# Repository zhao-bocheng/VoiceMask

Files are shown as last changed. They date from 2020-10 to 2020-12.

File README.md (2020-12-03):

# Voice Mask

该面罩是基于Arduino Nano制作的一款声控灯光面罩，面罩的灯光图案可以根据声音的变化而变化，模仿说话时的嘴部动作，另外还能通过声音控制显现一个简单的微笑。附带有颜色随身边温度变化、颜色自定义、静态图像切换的小功能。（[*演示视频*](./video/voiceMask.mp4)）

## 功能介绍

### 1. 显示模式

显示模式有两种：动态和静态。
a) 动态模式下说话时图案会根据声音大小不同进行不同的变化，当发出一个短促的声音并且一定时间内无其他声响，会显露一个“微笑”；（[*演示视频*](./video/voiceMask.mp4)）
b) 静态（禁言）模式下可以切换三种静态图像：“禁止标志”、风车、爱心

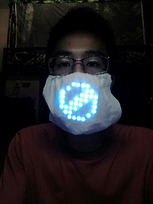
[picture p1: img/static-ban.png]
Ban 禁止标志
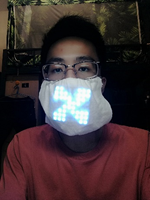
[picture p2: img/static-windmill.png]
Windmill 风车图案
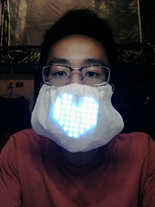
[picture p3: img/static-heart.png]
heart 爱心图案


### 2. 颜色模式

颜色模式有两种：温变模式和自定义模式。
a) 温变模式下，颜色会时刻根据当下温度进行变化：随着温度升高灯光颜色偏向暖色调，随着温度降低灯光颜色偏向冷色调，可以间接的反应温度变化（y源代码中将温度区间设置为10到40摄氏度）；\
b) 自定义模式下可以自定义当前颜色，这种模式下颜色固定为所调节的颜色（颜色范围为彩虹色，没有白光）

### 补充说明

a) 以上个功能（模式）的切换和使用通过面罩上的按钮进行；\
b) 每次断电后开发板会记住上次断电前面罩所处状态；\
c) 该程序由两个程序组成:主程序和附属程序。附属程序“putDataIntoEEPROM.ino”用于向EEPROM写入一些状态值，以设置默认的初始状态（对于未下载过该程序的开发板最好先下载“putDataIntoEEPROM.ino”来对EEPROM中的数据进行初始化）

## 硬件需求

| **设备** | **数量** |
| :---: | :---: |
| Arduino Nano | 1 |
| 立式轻触按键 | 若干 |
| 8x8WS2812点阵 | 1 |
| 面包线、跳线等导线 | 若干 |
| 面包板（主要用于测试阶段） | 1 |
| 10k电阻 | 1 |
| NTC热敏电阻 | 1 |
| MAX4466声音传感器 | 1 |
| 洞洞板（用于承载按键，尺寸按情况决定） | 1 |
| 可透光、透气且有一定韧性的布料 | 尺寸自定 |
| 9V电池 | 1 |
| 9V电池扣 | 1 |
| 5v输出降压模块 | 1 |
| 热缩管 | 若干 |
| 焊锡工具 | 配套工具若干 |

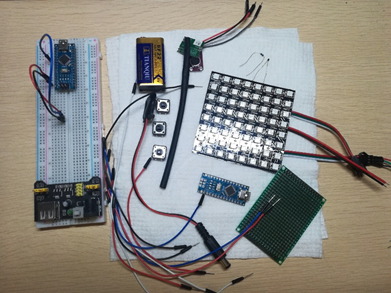
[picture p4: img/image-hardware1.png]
hardware 使用的硬件


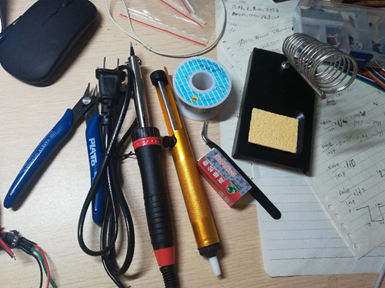
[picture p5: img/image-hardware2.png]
hardware 使用的硬件


## 软件需求

Arduino IDE: Arduino IDE 要与Arduino单片机型号配套（这里为Arduino Nano），其支持C/C++开发语言且可以同时兼容两种语言，易上手。该代码编写需要引入以下库：

```c
#include <Adafruit_GFX.h>
#include <Adafruit_NeoPixel.h>
#include <Adafruit_NeoMatrix.h>
#include <gamma.h>
#include <math.h>
#include <EEPROM.h>
```

fritzing（可选）：用于绘制原理图。

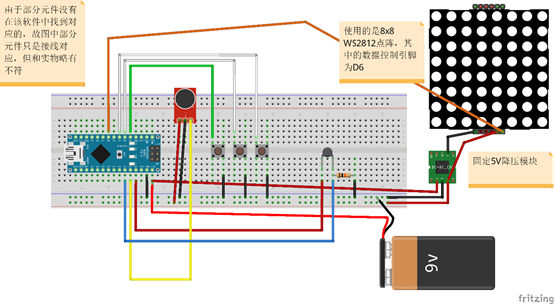
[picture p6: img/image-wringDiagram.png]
Wring Diagram 绘制的接线图


## 制作成果展示

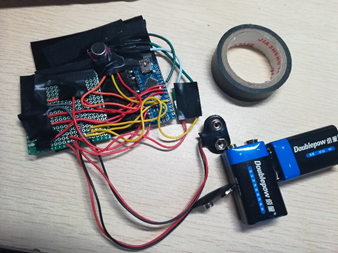
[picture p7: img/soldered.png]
soldered 半成品


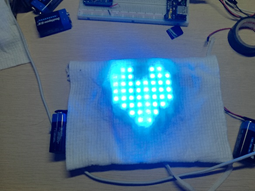
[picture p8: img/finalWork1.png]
final work 成品


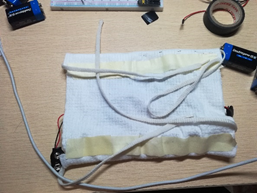
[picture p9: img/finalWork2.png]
fianl work 成品


final work 成品

*制作过程不做赘述，可参考库中的[设计工作记录](./设计工作记录.pdf)*

## 存在问题

即使最后的成品是以两个9V的电池供电，仍因为电力消耗大容易导致电力不足，继而使灯光效果出现瑕疵。另外，在面罩上加装9V电池，实属突兀。

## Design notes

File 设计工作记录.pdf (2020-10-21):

### 设计工作记录

周次 | 时间 | 设计进展概述 | 阶段成果截图 | 思考、讨论和改进意见

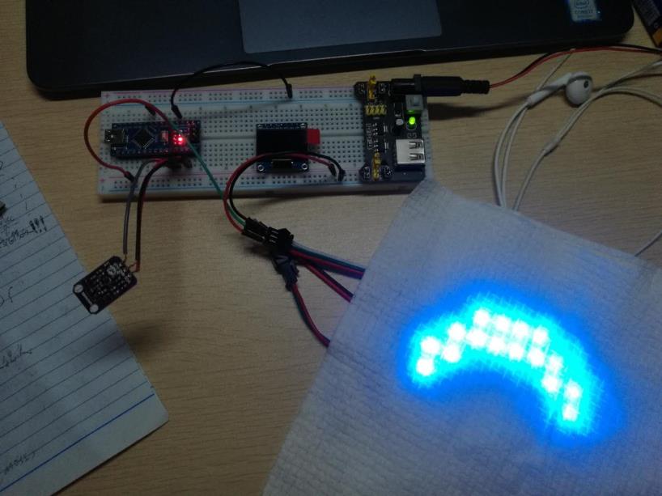
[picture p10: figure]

一 | 8.28

制作 voice mask 最基本功
能：动态功能——说话时点
阵会发生图像变化，并已经
可以根据声音做出一个简单
“微笑”

最基本的功能已经实现，但代
码步骤略显繁琐，需要精简基
本功能代码；考虑增添一些附
加功能

### 设计工作记录

周次 | 时间 | 设计进展概述 | 阶段成果截图 | 思考、讨论和改进意见

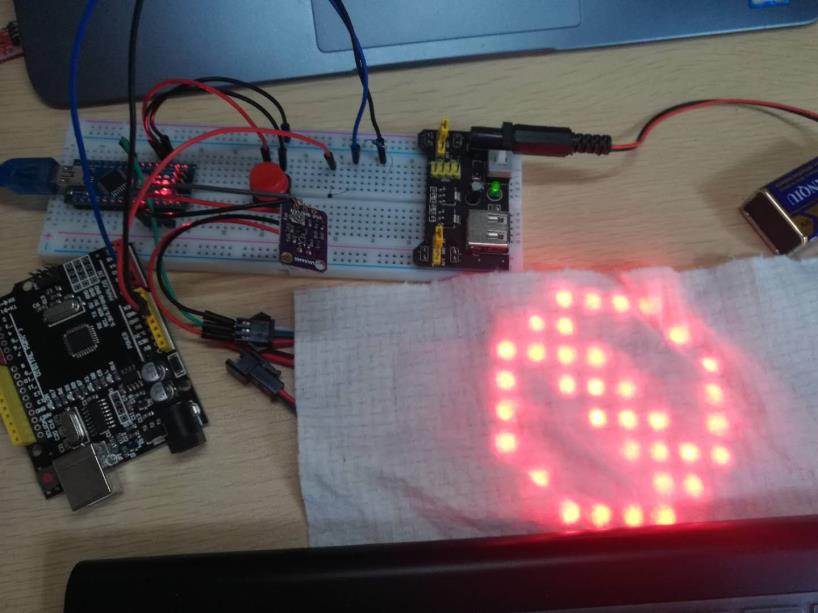
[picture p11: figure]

一 | 8.29

精简了“动态模式”的相关
代码，增添了一个“静态模
式”，“动态模式”和“静
态模式”可以通过红色按钮
切换

功能添加成功，但代码中对颜
色值的赋予似乎略显繁琐，待
改进；代码量变多，程序代码
结构略显混乱

### 设计工作记录

周次 | 时间 | 设计进展概述 | 阶段成果截图 | 思考、讨论和改进意见
一 | 8.29

修改代码中的颜色赋予步
骤；将“动态模式”和“静
态模式”相关代码精简，暂
时不考虑将这两个模式的代
码模块化为函数，担心不断
地调用函数会影响连续的动
态效果

颜色始终固定，考虑配合已有
的 NTC 热敏电阻开发出可以根
据温度变化颜色的功能

### 设计工作记录

周次 | 时间 | 设计进展概述 | 阶段成果截图 | 思考、讨论和改进意见

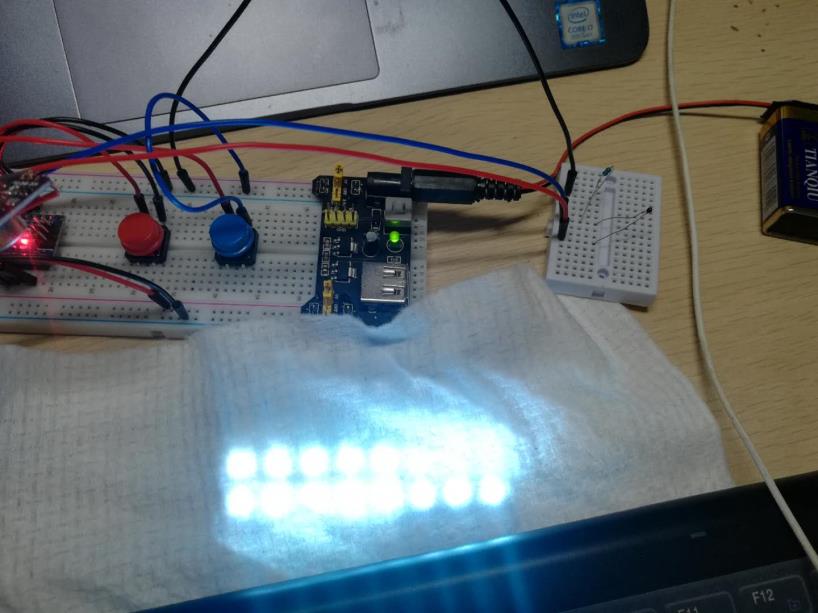
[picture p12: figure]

一 | 8.30

基本实现颜色随温度变化的
功能，可以通过蓝色按钮进
行该功能的开关

原先设想的是：随着温度升高
灯光颜色偏向暖色调，随着温
度降低灯光颜色偏向冷色调，
但展现出的效果并非如此，需
要改变有关于根据温度值变化
计算出的颜色值的算法（现有
算法仅为 currentColor =
map(temperature, minTemp,
maxTemp, 0x1F, 0xF800),0x1F 为十六位颜色的蓝色，0xF800
位红色）

### 设计工作记录

周次 | 时间 | 设计进展概述 | 阶段成果截图 | 思考、讨论和改进意见

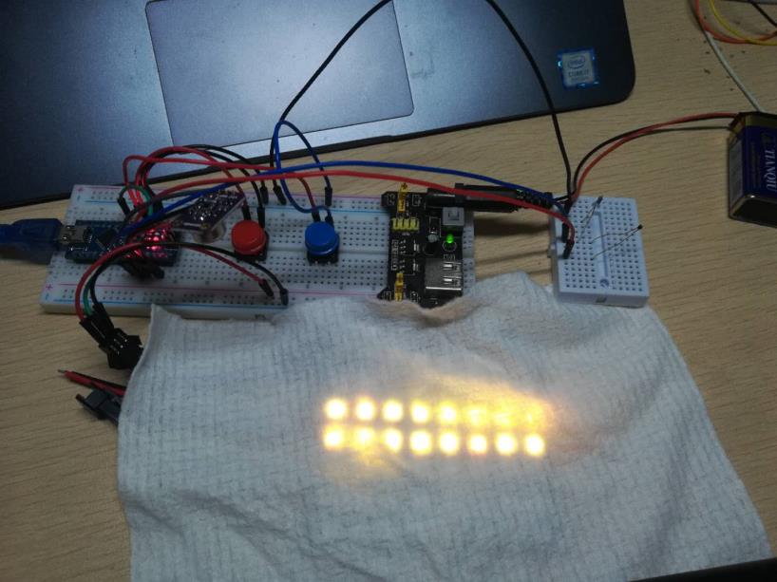
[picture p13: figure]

一 | 8.31

将颜色值随温度变化的算法
进行了修改，并整合到了
getColor()函数中（详见源
代码）

此时“动态模式”出现迟缓现
象，需要进一步优化代码

### 设计工作记录

周次 | 时间 | 设计进展概述 | 阶段成果截图 | 思考、讨论和改进意见

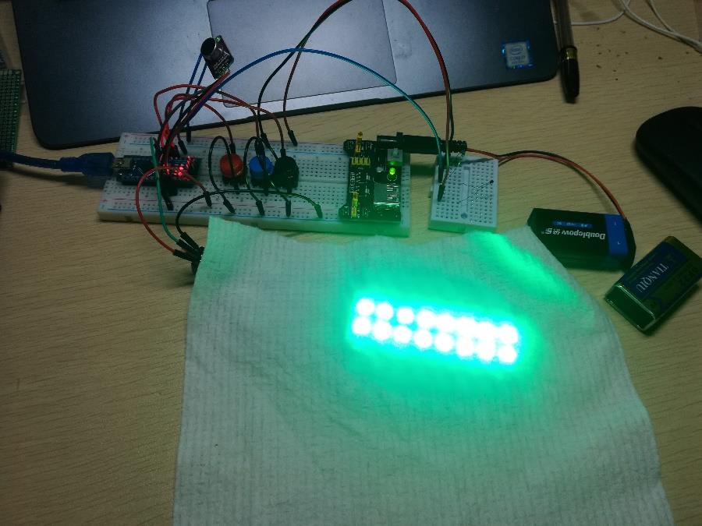
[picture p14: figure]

一 | 9.1

将先前的所有各功能进行了
模块化，都整合到了各自函
数里，并针对使用的各个变
量的不同性质，将可以放入
flash 空间的数据放入，尽
量减少对 SRAM 的占用，动
态效果得到了很大改善；在
修改代码的同时我添加了之
前忽略掉的颜色调节，可以
通过黑色按钮在彩虹色中选
择颜色，没有白光，当处于
“温变模式”时，无法自行
改变颜色

设想的是按照彩虹色的顺序，
由蓝到红，再经过紫色回到蓝
的顺序单向调节想要的颜色，
但是调节过程中颜色略有跳跃
和缺失

### 设计工作记录

周次 | 时间 | 设计进展概述 | 阶段成果截图 | 思考、讨论和改进意见

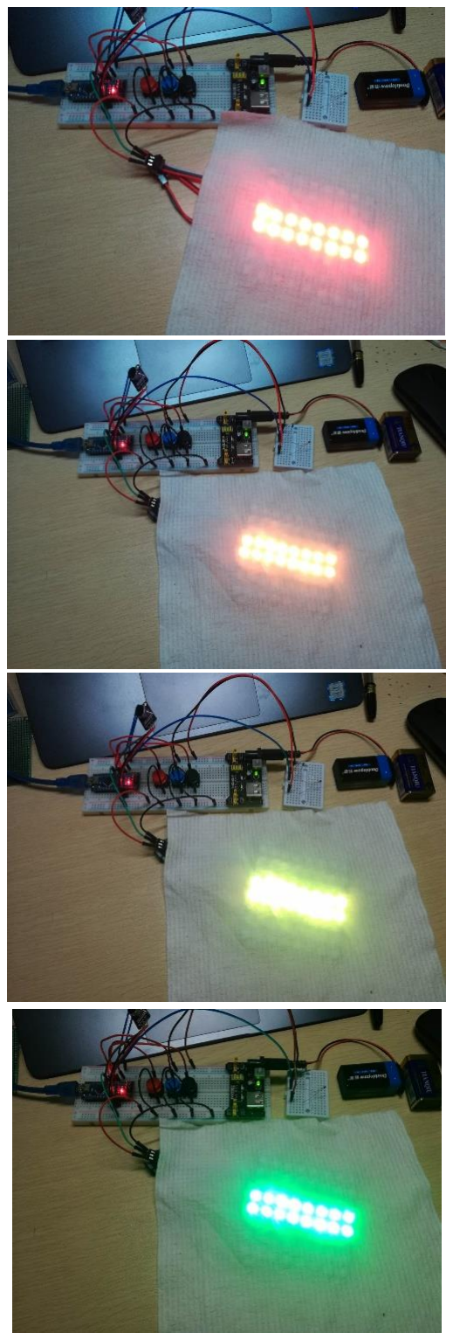
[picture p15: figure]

一 | 9.2

修改了变化颜色的算法，并
整合到了 getColor()函数
中，进一步精简代码，成功
实现颜色变化的设想顺序，
并且能得到许多介于七色之
间的颜色

基本设想已经基本实现，考虑
如何焊接并制作面罩

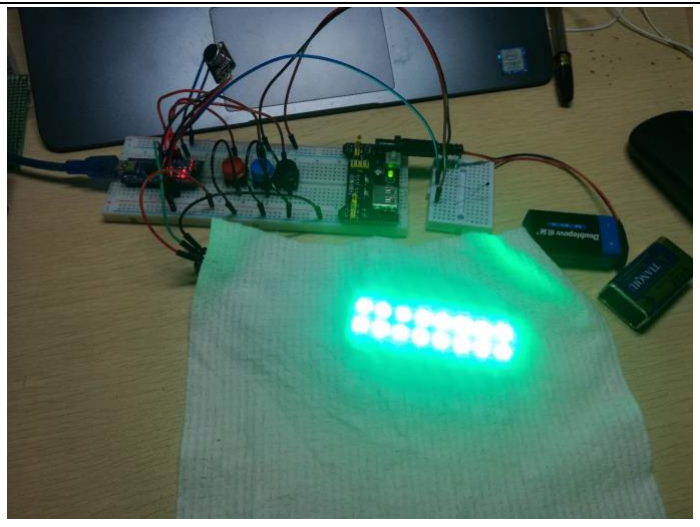
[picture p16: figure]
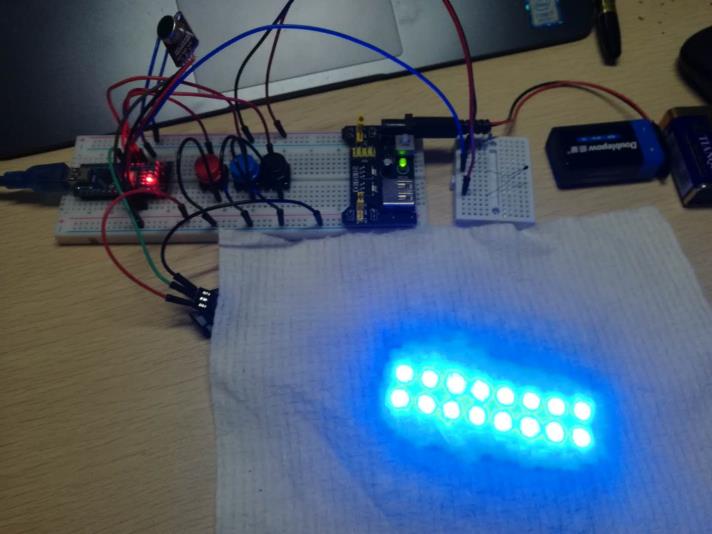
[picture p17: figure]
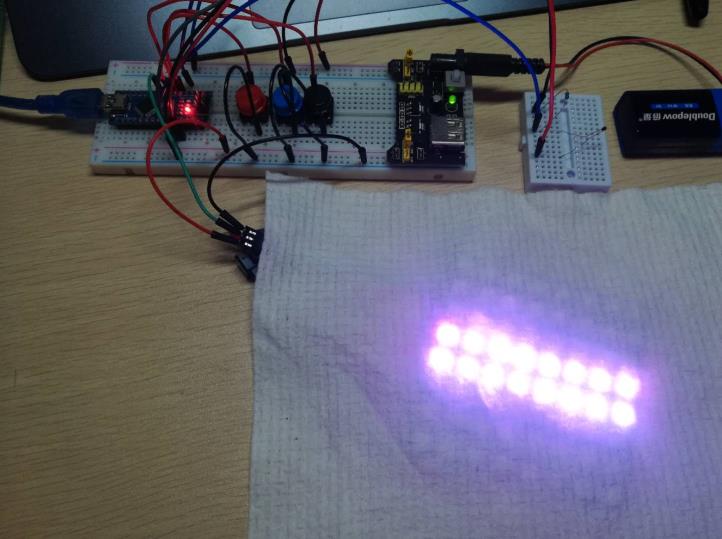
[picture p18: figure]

### 设计工作记录

周次 | 时间 | 设计进展概述 | 阶段成果截图 | 思考、讨论和改进意见

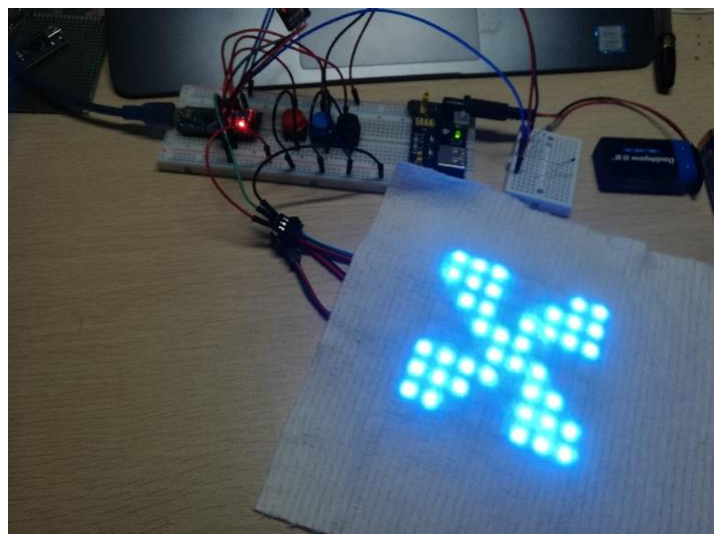
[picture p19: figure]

一 | 9.3

为静态模式增添多了两个静
态图案，现共三个静态图
案，通过红色按钮调节

准备焊接，并整合到面罩布料
中；另外由于每次断电后再接
电时数据就恢复为初始值，不
具有“记忆”，应寻求解决方
案

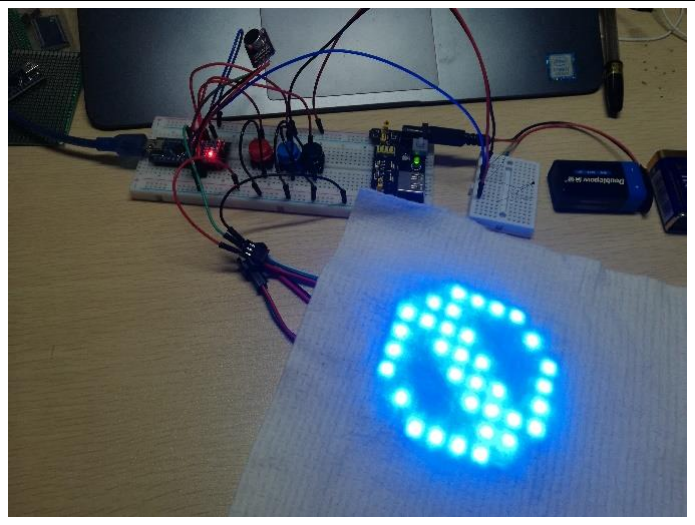
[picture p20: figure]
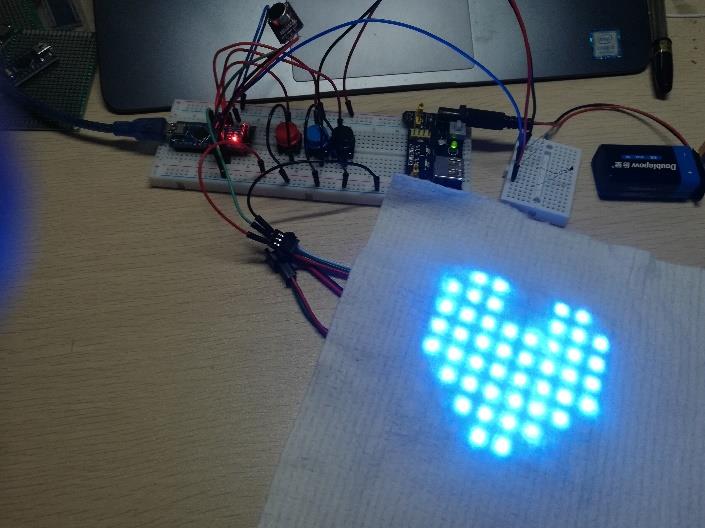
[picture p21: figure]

### 设计工作记录

周次 | 时间 | 设计进展概述 | 阶段成果截图 | 思考、讨论和改进意见
一 | 9.4

利用开发板的 EEPROM，将
颜色 RGB 值、模式状态值写
入其中，实现数据值断电后
不丢失的效果，为了初始化
这些特定值，需要在上传主
程序前上传一个附属程序
“putDataIntoEEPROM.ino
”，同时主程序代码步骤中
添加了相应的 EEPROM 读写
操作

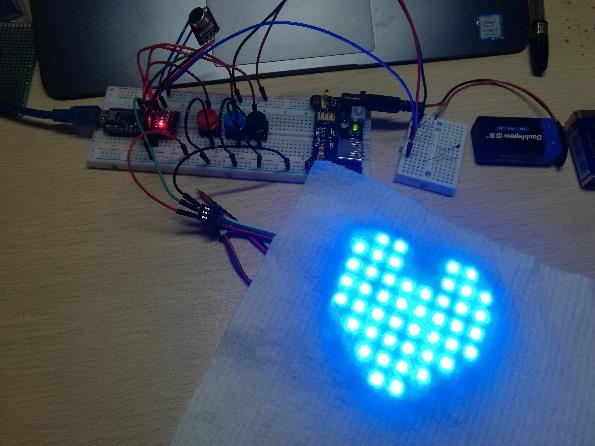
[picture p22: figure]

初始状态

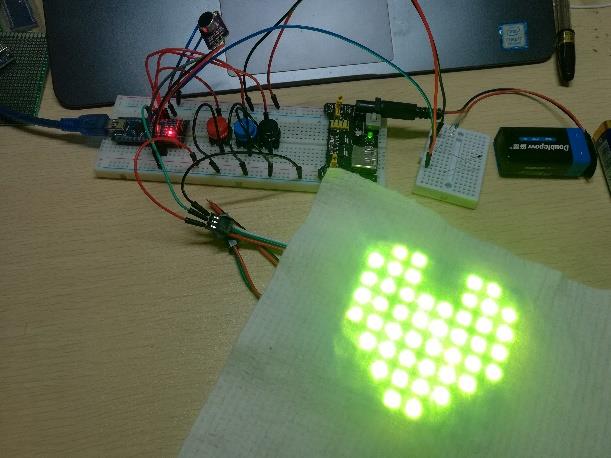
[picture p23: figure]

断电前

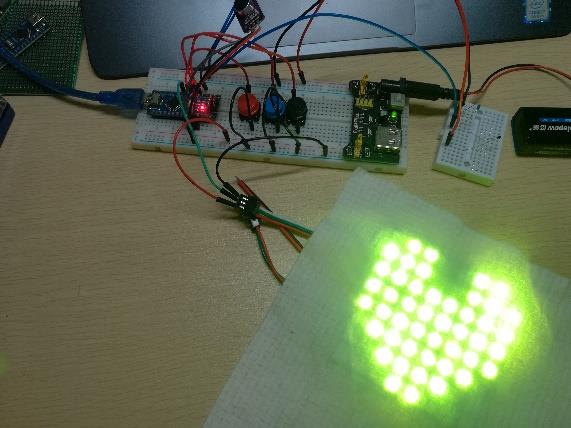
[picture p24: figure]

断电后再次接电

准备焊接，并整合到面罩布料
中

### 设计工作记录

周次 | 时间 | 设计进展概述 | 阶段成果截图 | 思考、讨论和改进意见

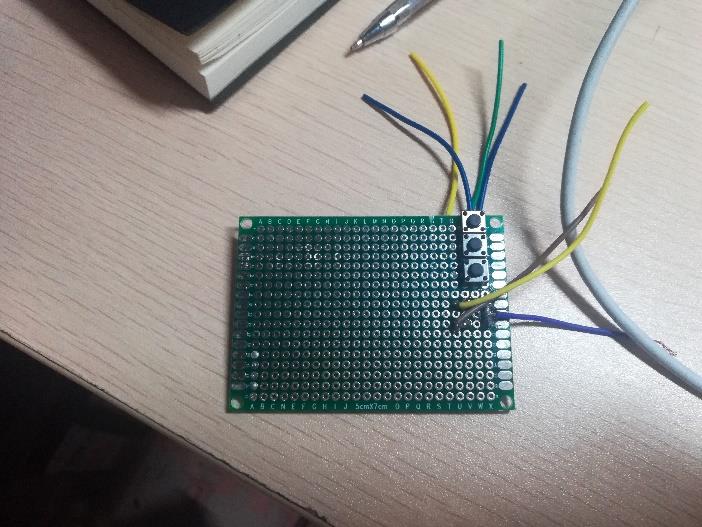
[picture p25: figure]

二 | 9.6 | 最后阶段——焊接所有元件

该焊接结果出现故障，并且使
用的电烙铁枪头氧化严重，导
致部分元件焊接时间过久因高
温而损坏，需要重新购买元件

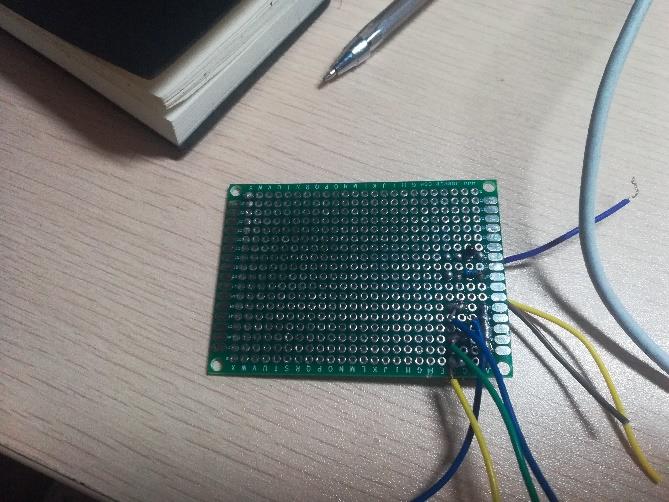
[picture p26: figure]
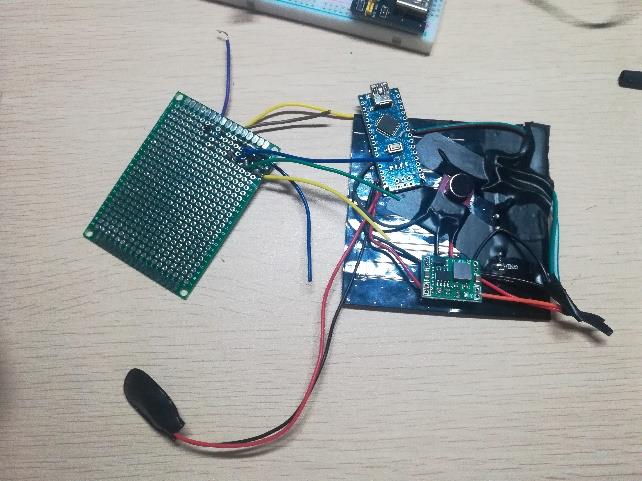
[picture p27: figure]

### 设计工作记录

周次 | 时间 | 设计进展概述 | 阶段成果截图 | 思考、讨论和改进意见

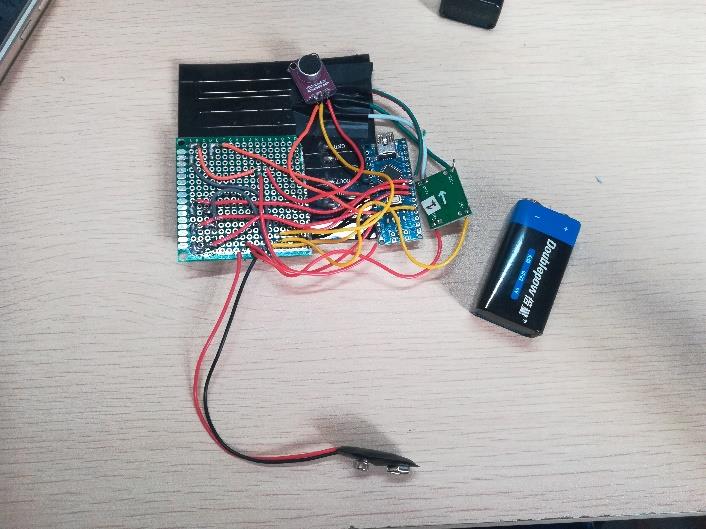
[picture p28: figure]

三 | 9.14 | 重新焊接所有元件

焊接完成，但是一个 9V 电池不
足以为所有元件供电，故需要
进行改进——打算再添加一个
9V 电池扣，以便一个 9V 电池
为 WS2812 点阵单独供电，另一
个 9V 电池为其他所有元件供电

### 设计工作记录

周次 | 时间 | 设计进展概述 | 阶段成果截图 | 思考、讨论和改进意见

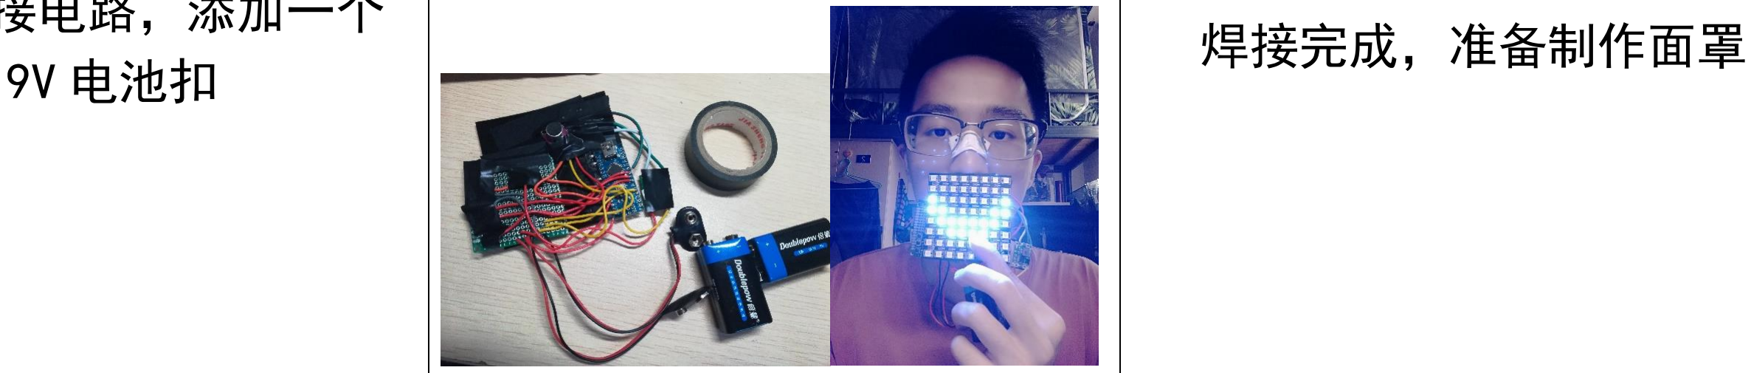
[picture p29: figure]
9V 电池扣; 焊接完成，准备制作面罩

三 | 9.15

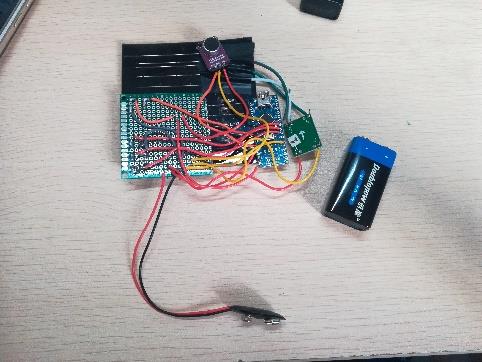
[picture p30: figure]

改进焊接电路，添加一个

### 设计工作记录

周次 | 时间 | 设计进展概述 | 阶段成果截图 | 思考、讨论和改进意见

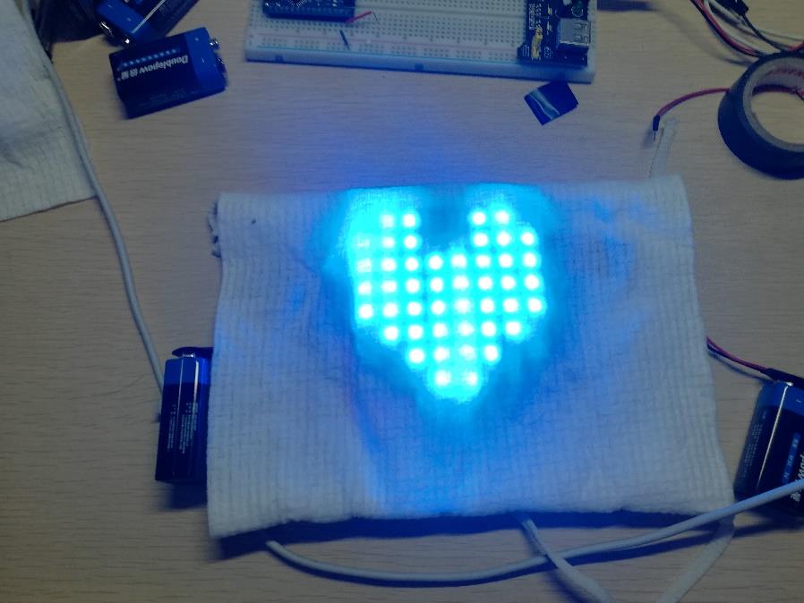
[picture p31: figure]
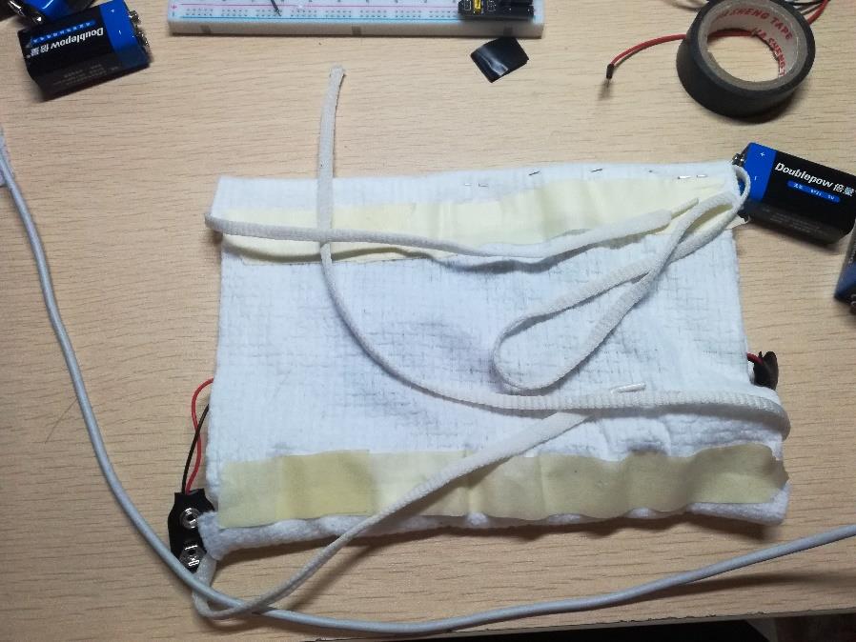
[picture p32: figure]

三 | 9.16

最后阶段（2）——面罩制
作

我的手工属实不忍直视

## 设计工作小结

学习经验：
不要在一个暂时无法解决的问题上纠结，出去找小
姐姐散散步也挺好，说不定回来就有灵感了

项目存在问题：
供电问题，通过 9V 电池为所有元件供电电量极易不
足，当电量不足时，灯光效果会出现偏差，尤其是颜
色；另外电源形式为一个立体长方体的 9V 电池，对一 个面罩来说实属突兀，应寻求体积更小、电量更足的
电源。
面罩透气性问题，由于面罩的正中就是一个方形密闭
材料的 WS2812 点阵，透气性显然很差，如果有条件， 或许可以把 WS2812 灯珠镶嵌在特定透气面料中，解 决透气性不足的问题。

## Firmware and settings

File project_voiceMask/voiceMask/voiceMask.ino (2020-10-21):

/*
 * 灯光面罩
 * 1、显示模式
 * 显示模式有两种：动态和静态
 * 动态模式下说话时图案会根据声音大小不同进行不同的变化，
 * 当发出一个短促的声音并且一定时间内无其他声响，会显露一个“微笑”
 * 静态（禁言）模式下可以切换三种静态图像：“禁止标志”、风车、爱心
 * 
 * 2、颜色模式
 * 颜色模式有两种：温变模式和自定义模式
 * 温变模式下，颜色会时刻根据当下温度进行变化：
 * 随着温度升高灯光颜色偏向暖色调，随着温度降低灯光颜色偏向冷色调，
 * 可以间接的反应温度变化
 * （以下代码中将温度区间设置为10到40摄氏度）
 * 自定义模式下可以自定义当前颜色，这种模式下颜色固定为所调节的颜色（颜色范围为彩虹色，没有白光）
 * 
 * 以上个功能（模式）的切换和使用通过面罩上的按钮进行
 * 
 * 每次断电后开发板会记住上次断电前面罩所处状态
 * 该程序有一个附属程序“putDataIntoEEPROM.ino”用于向EEPROM写入一些状态值，以设置默认的初始状态
 * （对于未下载过该程序的开发板最好先下载“putDataIntoEEPROM.ino”来对EEPROM中的数据进行初始化）
 * 
 */ 
#include <Adafruit_GFX.h>
#include <Adafruit_NeoPixel.h>
#include <Adafruit_NeoMatrix.h>
#include <gamma.h>
#include <math.h>
#include <EEPROM.h>

//以下为表情图案
const PROGMEM uint8_t mouth_0[8][8] = {
  {0,0,0,0,0,0,0,0},
  {0,0,0,0,0,0,0,0},
  {0,0,0,0,0,0,0,0},
  {6,6,6,6,6,6,6,6},
  {6,6,6,6,6,6,6,6},
  {0,0,0,0,0,0,0,0},
  {0,0,0,0,0,0,0,0},
  {0,0,0,0,0,0,0,0}
};

const PROGMEM uint8_t mouth_1[8][8] = {
  {0,0,0,0,0,0,0,0},
  {0,0,0,0,0,0,0,0},
  {0,0,0,6,6,0,0,0},
  {6,6,6,0,0,6,6,6},
  {6,6,6,0,0,6,6,6},
  {0,0,0,6,6,0,0,0},
  {0,0,0,0,0,0,0,0},
  {0,0,0,0,0,0,0,0}
};

const PROGMEM uint8_t mouth_2[8][8] = {
  {0,0,0,0,0,0,0,0},
  {0,0,0,0,0,0,0,0},
  {0,6,6,6,6,6,6,0},
  {6,0,0,0,0,0,0,6},
  {6,0,0,0,0,0,0,6},
  {0,6,6,6,6,6,6,0},
  {0,0,0,0,0,0,0,0},
  {0,0,0,0,0,0,0,0}
};

const PROGMEM uint8_t mouth_3[8][8] = {
  {0,0,0,0,0,0,0,0},
  {0,0,6,6,6,6,0,0},
  {0,6,0,0,0,0,6,0},
  {6,0,0,0,0,0,0,6},
  {6,0,0,0,0,0,0,6},
  {0,6,0,0,0,0,6,0},
  {0,0,6,6,6,6,0,0},
  {0,0,0,0,0,0,0,0}
};

const PROGMEM uint8_t mouth_4[8][8] = {
  {0,0,6,6,6,6,0,0},
  {0,6,0,0,0,0,6,0},
  {6,0,0,0,0,0,0,6},
  {6,0,0,0,0,0,0,6},
  {6,0,0,0,0,0,0,6},
  {6,0,0,0,0,0,0,6},
  {0,6,0,0,0,0,6,0},
  {0,0,6,6,6,6,0,0}
};

const PROGMEM uint8_t mouth_smile[8][8] = {
  {0,0,0,0,0,0,0,0},
  {0,0,0,0,0,0,0,0},
  {6,0,0,0,0,0,0,6},
  {6,6,0,0,0,0,6,6},
  {0,6,6,6,6,6,6,0},
  {0,0,6,6,6,6,0,0},
  {0,0,0,0,0,0,0,0},
  {0,0,0,0,0,0,0,0}
};

const PROGMEM uint8_t mouth_ban[8][8] = {
  {0,0,6,6,6,6,0,0},
  {0,6,6,0,0,0,6,0},
  {6,6,6,6,0,0,0,6},
  {6,0,6,6,6,0,0,6},
  {6,0,0,6,6,6,0,6},
  {6,0,0,0,6,6,6,6},
  {0,6,0,0,0,6,6,0},
  {0,0,6,6,6,6,0,0}
};

const PROGMEM uint8_t mouth_cross[8][8] = {
  {6,6,6,0,0,0,6,6},
  {6,6,6,0,0,6,6,6},
  {0,6,6,0,6,6,6,6},
  {0,0,6,6,6,0,0,0},
  {0,0,0,6,6,6,0,0},
  {6,6,6,6,0,6,6,0},
  {6,6,6,0,0,6,6,6},
  {6,6,0,0,0,6,6,6}
};

const PROGMEM uint8_t mouth_heart[8][8] {
  {0,6,6,0,0,6,6,0},
  {6,6,6,0,0,6,6,6},
  {6,6,6,6,6,6,6,6},
  {6,6,6,6,6,6,6,6},
  {6,6,6,6,6,6,6,6},
  {0,6,6,6,6,6,6,0},
  {0,0,6,6,6,6,0,0},
  {0,0,0,6,6,0,0,0}
};

const PROGMEM int imageTotal = 4; //图案显示种类, mouth_(num|smile)  mouth_ban  mouth_cross  mouth_heart

const PROGMEM int micPin = A7;  //声音传感器模拟输入引脚
const PROGMEM int matrixPin = 6;  //对WS2812点阵的数据输出引脚

//显示模式转换按钮相关变量
int imageNum;  //图像模式
const PROGMEM int displayModePin = 2; //显示模式切换按钮引脚

//颜色模式转换按钮相关变量
bool ifChange;  //颜色是否随温度改变
const PROGMEM int colorModePin = 3; //颜色模式切换按钮引脚
const PROGMEM int tempPin = A6; //温度传感器模拟值输入
//颜色随温度的变化范围
const PROGMEM int minTemp = 10; //celsius
const PROGMEM int maxTemp = 40;
//颜色变换按钮相关变量
const PROGMEM int colorChangePin = 4; //颜色值改变按钮引脚

//定义一个8x8WS2812点阵对象
Adafruit_NeoMatrix matrix = Adafruit_NeoMatrix(8, 8, matrixPin,
  NEO_MATRIX_TOP     + NEO_MATRIX_RIGHT +
  NEO_MATRIX_ROWS    + NEO_MATRIX_ZIGZAG,
  NEO_GRB            + NEO_KHZ800);
  
//颜色值已经用另一个程序“putColorIntoEEPROM.ino”写入EEPROM

void setup() {
  //设置各功能按钮引脚状态
  pinMode(displayModePin, INPUT_PULLUP);
  pinMode(colorModePin, INPUT_PULLUP);
  pinMode(colorChangePin, INPUT_PULLUP);

  //从EEPROM中读取数据
  EEPROM.get(3, ifChange);
  EEPROM.get(4, imageNum);

  //初始化点阵
  matrix.begin();

  //Serial.begin(9600);
}

void loop() {
  //动态模式
  imageNum = dynamicMode(imageNum, displayModePin);
  //禁言模式
  imageNum = banningMode(imageNum, displayModePin);
} 


//通过NTC热敏电阻的输入模拟值计算当前温度
double themistor(int rawADC) {
  double temp;
  temp = log((10240000/(rawADC)) - 10000);
  temp = 1/(0.001129148 + (0.000234125 + (0.0000000876741 * temp * temp)) * temp);
  temp = temp - 273.15;
  return temp;
}

//获取颜色
uint16_t getColor(bool ifChange) {
  uint8_t rval, gval, bval;
  //按不同的颜色模式处理rgb值
  if(ifChange) {
    //减小温度值的波动
    int samples = 128;
    long analog = 0;
    for(int i = 0; i < samples; i ++) {
      analog += analogRead(tempPin);
    }
    analog = analog / samples;
    double temperature = themistor((int)analog); //去多个模拟值的平均值，减小温度值波动
    //根据温度不同进行不同处理
    if(temperature < minTemp) {
      rval = 0;
      gval = 0;
      bval = 255;
    }else if(temperature > maxTemp) {
      rval = 255;
      gval = 0;
      bval = 0;
    }else {
      rval = map(temperature, minTemp, maxTemp, 0, 255);
      bval = map(temperature, minTemp, maxTemp, 255, 0);
      gval = 510 - rval - bval;
    }
  }else {
    //取得颜色值
    EEPROM.get(0, rval);  
    EEPROM.get(1, gval);
    EEPROM.get(2, bval);
    int ifValChange = digitalRead(colorChangePin);
    if(ifValChange == 0){
      if(bval == 255 && gval != 255 && rval == 0) {
        gval += 5;
      }else if(bval != 0 && gval == 255) {
        bval -= 5;
      }else if(gval == 255 && rval !=255) {
        rval += 5;
      }else if(gval != 0 && rval == 255) {
        gval -= 5;
      }else if(rval == 255 && bval != 255) {
        bval += 5;
      }else if(rval != 0 && bval == 255) {
        rval -= 5;
      }
      //记录新的颜色值
      EEPROM.put(0, rval);  
      EEPROM.put(1, gval);
      EEPROM.put(2, bval);
      
      //delay(10); //debounce
    }
  }
  uint16_t colorval = matrix.Color(rval, gval, bval);
  return colorval;
}

//显示相应图案
void drawImage(short image_addr, bool ifChange){
  uint16_t currentColor; //当前颜色
  //判断颜色是否随温度变化,并按对应模式给予颜色
  currentColor = getColor(ifChange);
  //给灯珠填充颜色
  for(int x = 0; x<8; x++){
    for(int y = 0; y<8; y++){
      //注意以下代码中来自avr/pgmspace.h的pgm_byte_xx()函数
      uint8_t index = pgm_read_byte_near(image_addr+x+y*8); //从flash程序空间中读取表情图案数据
      //uint8_t index = pgm_read_byte((short)mouth_ban+x+y*8);
      //uint16_t currentColor;// = pgm_read_word_near(palette + index);
      
      //向位于(x,y)的点写入颜色
      if(index == 0) {
        matrix.drawPixel(x, y, (uint16_t)0x0); 
      }else {
        matrix.drawPixel(x, y, currentColor);
      }
    }
  }
  matrix.show();
}

//动态模式
int dynamicMode(int imageNum, int disPlayModePin) {
  int popDetection = 0; //检测到符合条件的峰值的次数
  const static int PROGMEM noDetectionT = 500; //ms 没有检测到符合条件峰值的间隔时间阈值
  bool smiling = false; //是否微笑状态
  const static int PROGMEM smileLasting = 2000; //ms 微笑保持时间
  unsigned long smiletimer = 0; //微笑保持时间计时
  unsigned long last_face = 0;  //上一次表情状态时间点
  
  const static int PROGMEM peakThreshold = 150; //峰值绝对值的阈值
  const static int PROGMEM mouth1Threshold = 150; //mouth_1的显示阈值
  const static int PROGMEM mouth2Threshold = 200; //mouth_2的显示阈值
  const static int PROGMEM mouth3Threshold = 300; //mouth_3的显示阈值
  const static int PROGMEM mouth4Threshold = 400; //mouth_4的显示阈值
  const static uint16_t PROGMEM samples = 128; //取128个模拟值样本
  const static int PROGMEM micThreshold = 512; //声音传感器阈值，实际操作时阈值大小大概在500到550间

  //切换按钮状态值
  int oldStateDisplay = 1;
  int newStateDisplay;

  int oldStateColor = 1;
  int newStateColor;
  
  while(imageNum == 0) {
    float micAbsPeak = 0; //峰值的绝对值
    for (int i = 0; i < samples; i ++){
      auto analog = analogRead(micPin);
      auto micLine = abs(analog - micThreshold);
      
      micAbsPeak = max(micLine, micAbsPeak);
    }
    
    if(micAbsPeak > peakThreshold){
      popDetection += 1;
      if(popDetection > 2) {
        smiling = false;
        last_face = millis();
      }
    }else{
      if(popDetection > 0 && popDetection <= 2) {
        if(millis() > last_face + noDetectionT){
          smiling = true;
          smiletimer = millis() + smileLasting;
        }
      }
      popDetection = 0; //这个很关键
    }
  
    if(millis() > smiletimer) 
      smiling = false;
  
    //以下的micAbsVal全部改用micAbsPeak
    if(smiling){
      drawImage((short)mouth_smile, ifChange);
    }else if(micAbsPeak < mouth1Threshold){
      drawImage((short)mouth_0, ifChange);
    }else if(micAbsPeak < mouth2Threshold){
      drawImage((short)mouth_1, ifChange);
    }else if(micAbsPeak < mouth3Threshold){
      drawImage((short)mouth_2, ifChange);
    }else if(micAbsPeak < mouth4Threshold){
      drawImage((short)mouth_3, ifChange);
    }else {
      drawImage((short)mouth_4, ifChange);
    }
    
    //显示模式切换按钮
    newStateDisplay = digitalRead(displayModePin);
    if(newStateDisplay == 1 && oldStateDisplay == 0){
      imageNum = (imageNum + 1) % imageTotal;
      EEPROM.put(4, imageNum);
    }
    oldStateDisplay = newStateDisplay;

    //颜色模式切换按钮
    newStateColor = digitalRead(colorModePin);
    if(newStateColor == 1 && oldStateColor == 0) {
      ifChange = !ifChange;
      EEPROM.put(3, ifChange);
    }
    oldStateColor = newStateColor;
  }
  return imageNum;
}

//禁言模式
int banningMode(int imageNum, int displayModePin) {
  //切换按钮状态值
  int oldStateDisplay = 1;
  int newStateDisplay;

  int oldStateColor = 1;
  int newStateColor;
  
  while(imageNum != 0) {
    if(imageNum == 1) {
      drawImage((short)mouth_ban, ifChange);  //禁止标志图案
    }else if(imageNum == 2) {
      drawImage((short)mouth_cross, ifChange); //X图案
    }else if(imageNum == 3) {
      drawImage((short)mouth_heart, ifChange); //X图案
    }
    //显示模式切换按钮
    newStateDisplay = digitalRead(displayModePin);
    if(newStateDisplay == 1 && oldStateDisplay == 0){
      imageNum = (imageNum + 1) % imageTotal;
      EEPROM.put(4, imageNum);
    }
    oldStateDisplay = newStateDisplay;

    //颜色模式切换按钮
    newStateColor = digitalRead(colorModePin);
    if(newStateColor == 1 && oldStateColor == 0) {
      ifChange = !ifChange;
    }
    oldStateColor = newStateColor;
  }
  return imageNum;
}

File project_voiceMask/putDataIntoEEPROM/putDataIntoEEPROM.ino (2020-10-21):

/*
 * putDataIntoEEFROM.ino
 * 这是一个初始化开发板EEPROM的程序，目的只是要把一个颜色值、模式状态放入
 */
#include <EEPROM.h>

void setup() {
  // put your setup code here, to run once:
  uint8_t rval = 0;
  uint8_t gval = 0;
  uint8_t bval = 255;
  int imageNum = 0;
  bool ifChange = true;
//  int address = 0;
  //写入EEPEOM
  EEPROM.put(0, rval);  
  EEPROM.put(1, gval);
  EEPROM.put(2, bval);
  EEPROM.put(3, ifChange);
  EEPROM.put(4, imageNum);
}

void loop() {
  // put your main code here, to run repeatedly:
  ;
}

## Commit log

2020-10-21 Add basic files of the project to this repository
    Add basic files of the project to this repository
    [voiceMask.fzz]
2020-12-03 Update README.md
    部分该换行的地方没有换行，因此作了一些格式调整
